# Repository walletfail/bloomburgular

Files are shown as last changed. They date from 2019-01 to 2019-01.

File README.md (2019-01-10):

# Bloomburgular -- the super micro fun implant

## Goals of the implant

The design of the implant had the following constraints:

- Could occur during the supply chain OR after customer has taken
  receipt of the drive (think red team or insider threat)
- Requires zero firmware
- Fits inside the Nano S
- Bypasses a core security function
- Few components (cheap and DIY)
- FUN to build and use (not bluetooth)

## Theory of Operation

When the selected RF signal is detected, the output is pulled low.

That's it.

## Parts:

- C1: DC Blocking CAP
- R3: Pot for voltage adjustment (see notes below)
- Q1: NPN Transistor
- R1: Bias resistor
- R2 & C2: Low pass filter

## Operating Tips

The only thing tuning this circuit is the antenna. Experiment with
different antennas for different frequencies! We used 17cm for decent
reception at 433MHz. At 433Mhz, we had a 50W transmitter around so
that was fun :)

For the pot, you can make your circuit more or less sensitive. We
adjusted ours so that the output (GPIO) came down to about 2.9V. If
the pot is too low, you'll need a strong signal and too high, it will
pull the GPIO low without any RF.

## Improvements

You can remove the put and put in your own voltage divider and that
will save 80 percent of the BoM. Worse case, you will have to tune by
reworking SMD resistors, which isn't so bad.

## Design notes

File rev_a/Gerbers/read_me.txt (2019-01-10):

Cryptotronix LLC
Kirill V. Belyayev
kirill@cryptotronix.com
SuperMicro PCB, Rev A
12/13/2018

Files included:
	super_micro_2018-12-13.zip		A zip file of all PCB gerbers

PCB Fab Requirements:
	- 2-Layer PCB Stackup
	- 1oz Top and Bottom Copper Thickness
	- Finish: Lead Free HASL
	- Soldermask on top and bottom
	- Silkscreen on top and bottom
	- PCB Thickness: 0.031"
	- PCB Material: FR-04

Gerber File Naming Conventions
	copper_top.gbr			    Top Copper
    solderpaste_top.gbr			Top Paste
    silkscreen_top.gbr		    Top Silkscreen
    soldermask_top.gbr		    Top Soldermask
    copper_bottom.gbr		    Bottom Copper
    solderpaste_bottom.gbr	    Bottom Paste
    silkscreen_bottom.gbr	    Bottom Silkscreen
    soldermask_bottom.gbr		Bottom Soldermask
    profile.gbr		            PCB Outline
    drills.xln			        Drill File, Excellon 24 format

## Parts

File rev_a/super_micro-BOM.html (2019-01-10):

Qty | Value | Device | Package | Parts | Description | MAN-PART_NUM | MANUFACTURER | SPICEPREFIX | VALUE
1 | 10.0K | R-US_R0603 | R0603 | R1 | RESISTOR, American symbol |  |  | R
1 | 100 | R-US_R0603 | R0603 | R2 | RESISTOR, American symbol |  |  | R
1 | 100K | 3312J-1-104E | 3312J | R3 | 100 kOhms 0.1W, 1/10W J Lead Surface Mount Trimmer Potentiometer Cermet 1 Turn Top Adjustment | 3312J-1-104E | Bourns Inc. |  | 100K
1 | 100p | C-EUC0603 | C0603 | C1 | CAPACITOR, European symbol |  |  | C
1 | 10n | C-EUC0603 | C0603 | C2 | CAPACITOR, European symbol |  |  | C
1 | MMBT3904-7-F | MMBT3904-7-F | SOT-23 | Q1 | TRANS NPN 40V 0.2A SMD SOT23-3 | MMBT3904-7-F | Diodes Inc.
4 | TEST-POINT40MIL | TEST-POINT40MIL | TEST-POINT-40MILL | TP1, TP2, TP3, TP4 | Various Test Points
1 | WF_LOGO_S | WF_LOGO_S | WF_LOGO_S | LOGO1 | Wallet Fail Logo

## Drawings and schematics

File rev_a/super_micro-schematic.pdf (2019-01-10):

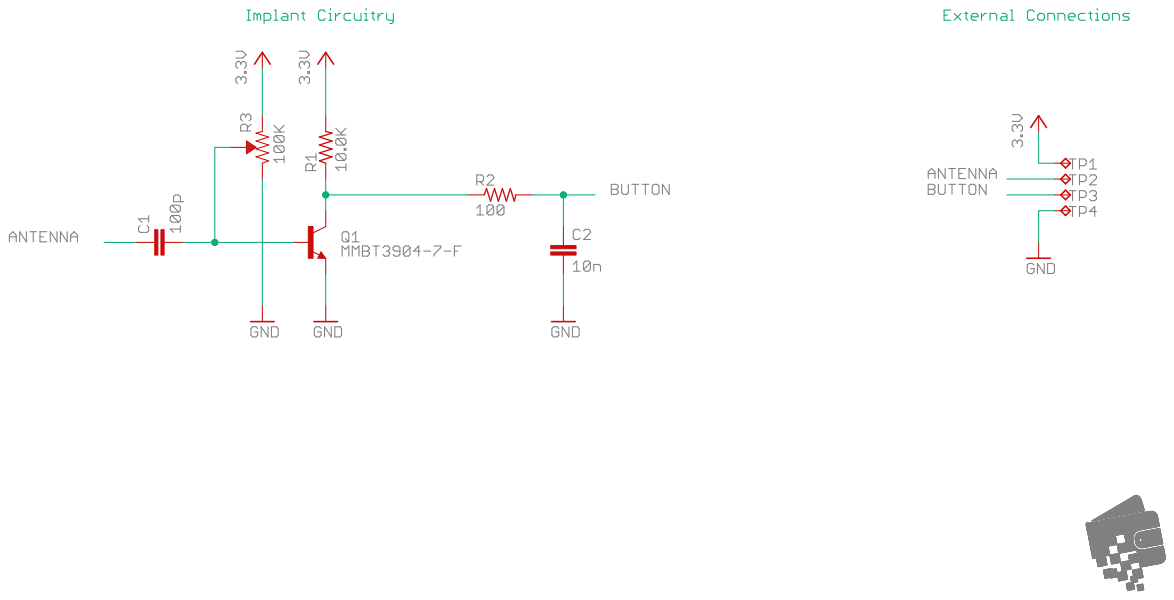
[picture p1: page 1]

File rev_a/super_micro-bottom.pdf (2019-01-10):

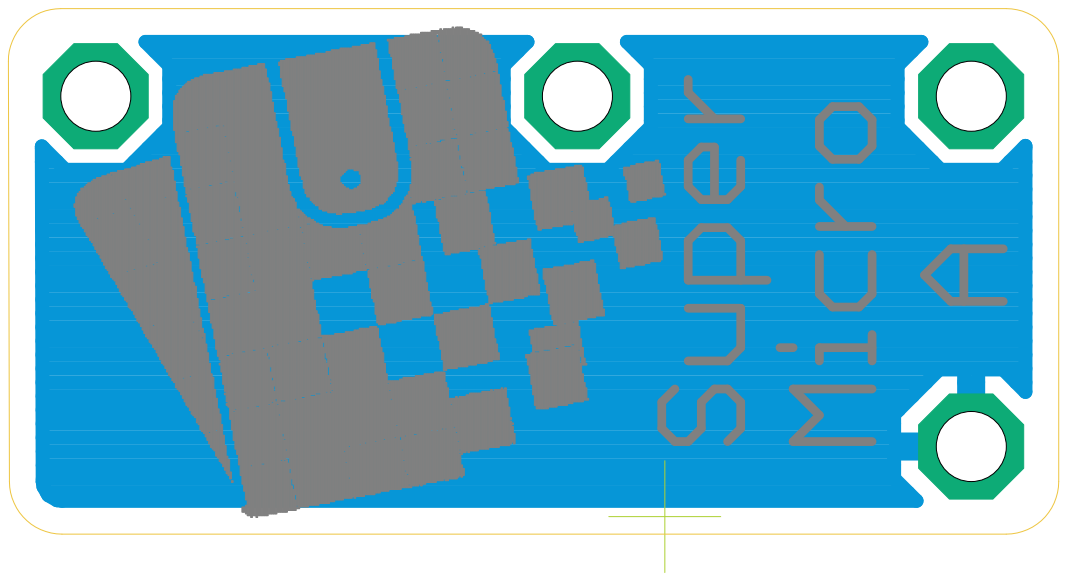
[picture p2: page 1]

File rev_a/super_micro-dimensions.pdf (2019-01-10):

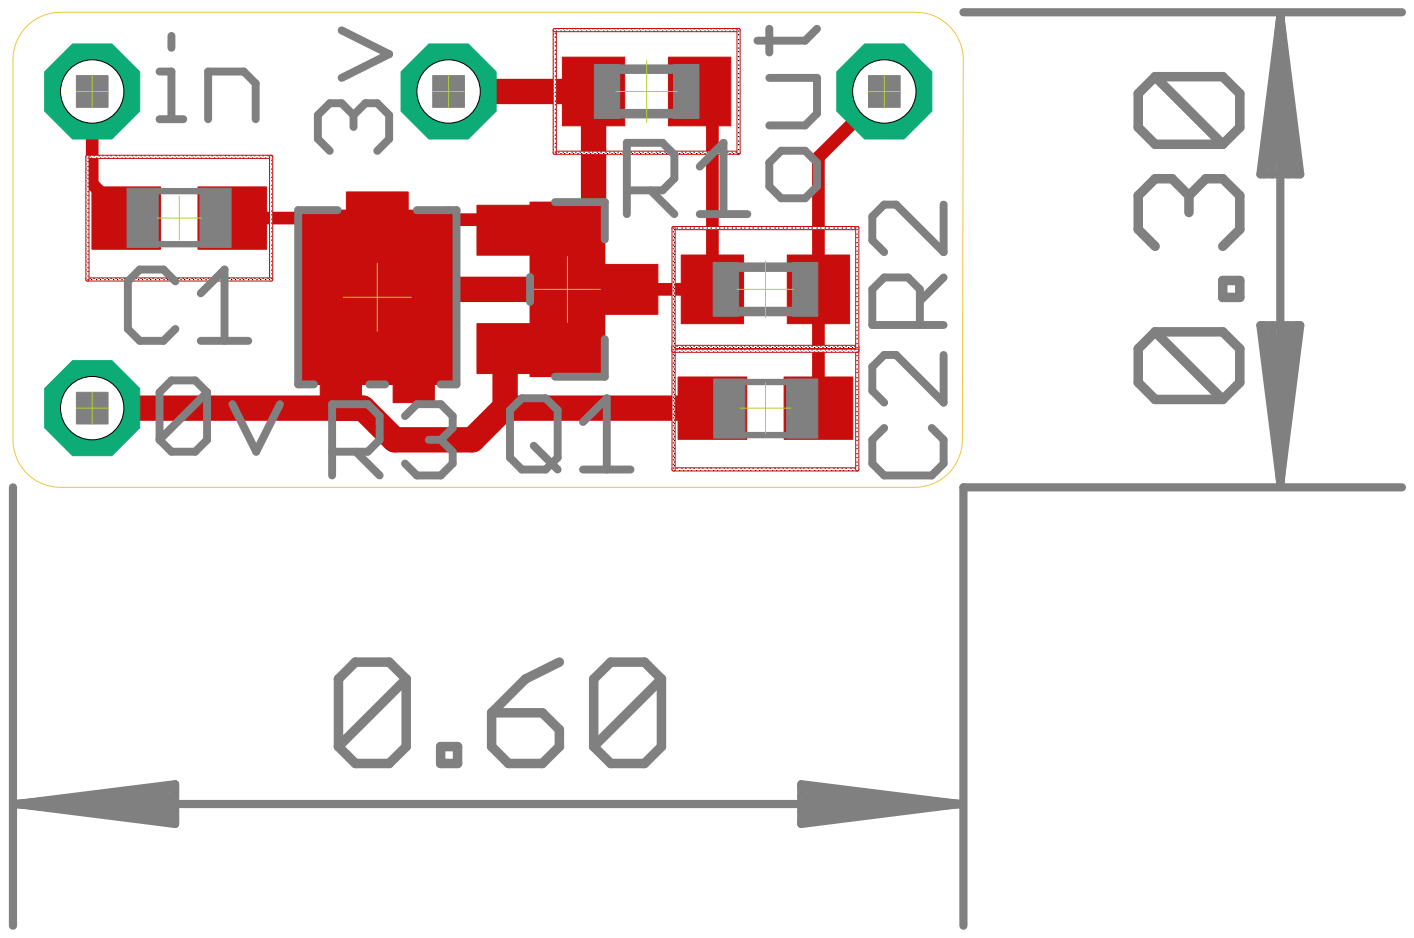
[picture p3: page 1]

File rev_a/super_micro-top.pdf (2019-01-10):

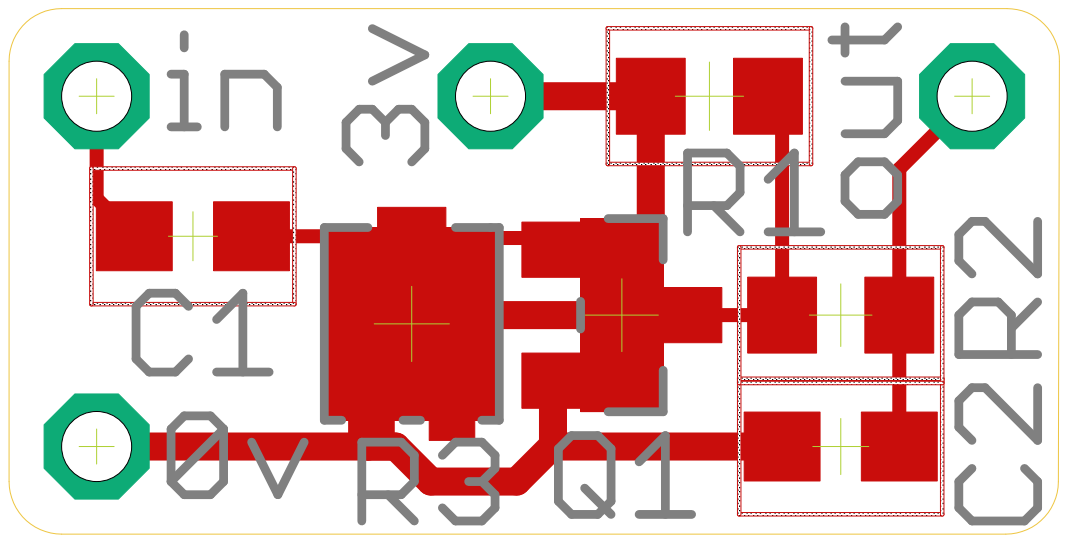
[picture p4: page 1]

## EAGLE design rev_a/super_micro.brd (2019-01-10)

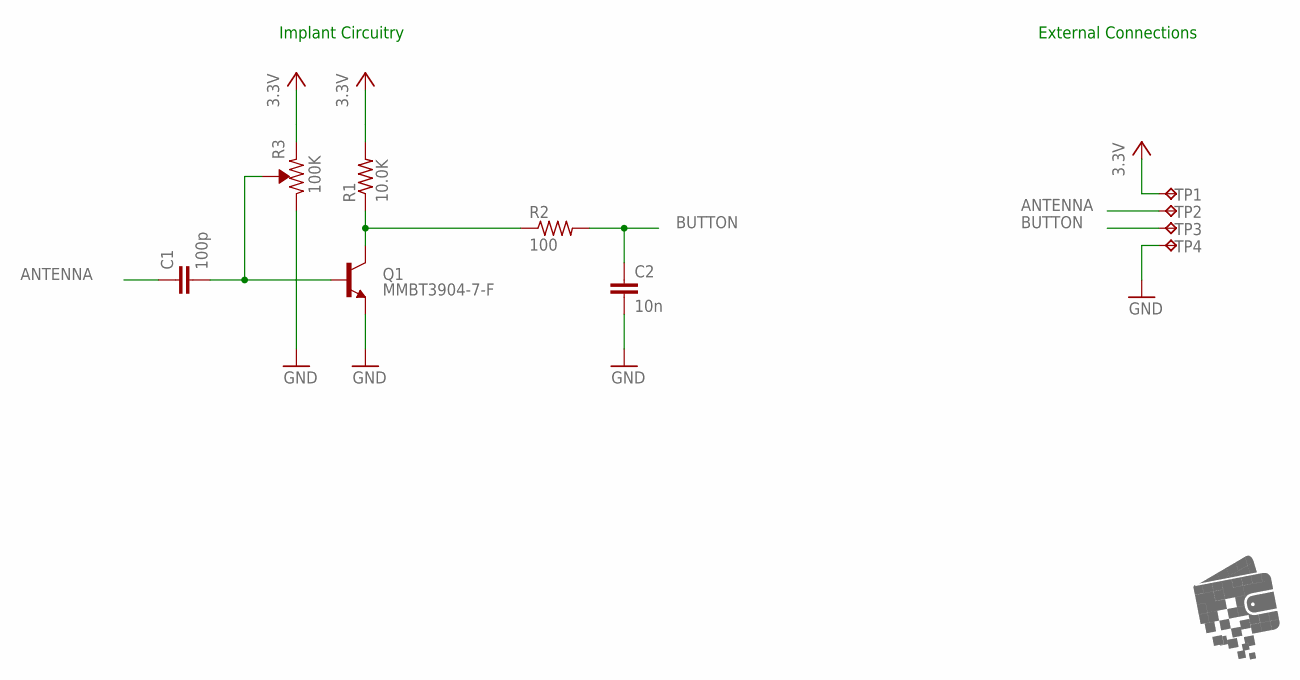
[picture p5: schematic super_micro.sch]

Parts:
C1: 100p; C0603
C2: 10n; C0603
LOGO1: WF_LOGO_S
Q1: MMBT3904-7-F; SOT-23
R1: 10.0K; R0603
R2: 100; R0603
R3: 100K; 3312J
TP1, TP2, TP3, TP4: TEST-POINT40MIL; TEST-POINT-40MILL

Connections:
0V: C2.2, Q1.2 (E), R3.1, TP4.1
3.3V: R1.2, R3.3, TP1.1
ANTENNA: C1.1, TP2.1
BUTTON: C2.1, R2.2, TP3.1
unnamed: Q1.3 (C), R1.1, R2.1
unnamed: C1.2, Q1.1 (B), R3.2

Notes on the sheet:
Implant Circuitry
External Connections

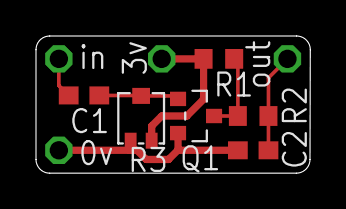
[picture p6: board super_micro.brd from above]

Board: 2 copper layers, 15.2 x 7.6 mm, 11 parts (1 on the bottom side), 6 nets.
